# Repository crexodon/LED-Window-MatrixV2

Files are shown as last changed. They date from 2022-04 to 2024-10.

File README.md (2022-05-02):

# LED-Window-Matrix Neo
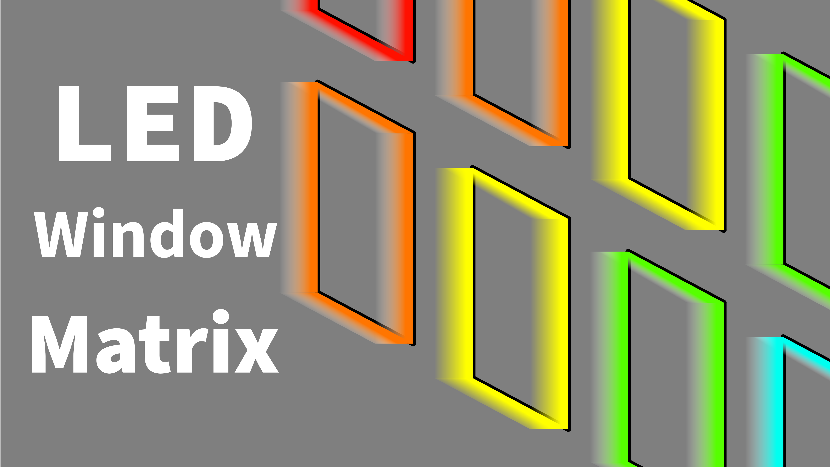
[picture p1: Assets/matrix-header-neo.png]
Header Image of Project

Complete new version of our last semester's [project](https://github.com/Boslx/LED-Window-Matrix). 

## New Features
- Complete rewrite of the mesh using ESP-MDF
- UDP based bridge for easy and fast communication
- Updated [PixelBridge](https://github.com/crexodon/PixelBridge)
- (Planned) Management Software for End User

## Old Media
https://user-images.githubusercontent.com/36489816/166237971-5a803816-1b47-4246-80e3-ec737a2a25ef.mp4

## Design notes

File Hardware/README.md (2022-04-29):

# Hardware
This folder contains our hardware designs for the matrix.

## Controller_Room
The room controller is a ESP32 PCB that features:  
- RS485 Transciever for the LEDs
- Power Switch and Sense
- Environment Sensors
- (Optional) LAN Interface
- (Optional) SD Card slot

## Controller_Window
The window controller is a WS2811 PCB that features:
- 2x RS485 Transciever for Data In and Out
- MosFETs to drive ~6m of RGB LED Strip

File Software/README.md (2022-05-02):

# Software
This folder contains the software for the matrix

## Mesh_Root
This is the root node of the mesh. It has a UDP Server to recieve packages from a user inside a wifi network and provides the relay to the mesh.

### UDP Protocol
The UDP protocol is still WIP, currently the structure is as follows:

```
 0  1  2  3  4  5  6  7  8  9 10
 
AA BB CC DD EE FF                   Target MAC
                  01                Command
                     00 01 02 ..    Payload
```

#### Commands
Command | Description | Payload | Example
--- | --- | --- | ---
0x01 | Set LED Data | Raw RGB LED data | `01 02 03 04 05 06 01 FF 00 00 00 FF 00 00 00 FF`
0x64 | Reset target node | N/A | `01 02 03 04 05 06 64`
0x65 | Initiate OTA (MAC is currently ignored) | Null terminated string of update URL | `00 00 00 00 00 00 65 http://192.168.1.100:8080/mesh_node.bin 00`

Commands can be easily sent with bash for testing, using echo and nc like this:  
`echo -ne "\x00\x00\x00\x00\x00\x00\x65http://192.168.1.100:8080/mesh_root.bin\x00" | nc -u -w0 192.168.1.42 7715`  

#### OTA Procedure

1. Build firmwares
2. **Upload node firmware to a local test node to see if it's still functional, before deploying to all nodes!**
3. Run `ota_fileserver.py`
4. Execute OTA UDP command with URL of OTA fileserver and path of firmware to update.
5. Depending of the filename of the update file, either the root or all nodes will be updated*

\* This behaviour will probably change in the future

## Mesh_Node
This is a mesh node. It can receive data from the mesh and parse them for the led control.

## PixelBridge
The [pixel bridge](https://github.com/crexodon/PixelBridge) is a fork of [LeoDJ's PixelBridge](https://github.com/LeoDJ/PixelBridge) that contains our contributions for this project. It is responsible for mapping the nodes to the rooms and also is a ArtNET endpoint for animations.

## Trinity
This is a management software that lets users control the matrix easier. It works together with the pixelbridge and also recieves data from the nodes' sensors
To Be Determined

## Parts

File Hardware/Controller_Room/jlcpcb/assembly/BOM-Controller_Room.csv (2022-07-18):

Comment | Designator | Footprint | LCSC
ACS711xLCTR-12AB | U4 | SOIC-8_3.9x4.9mm_P1.27mm | C114267
31,25k | R10 | R_0402_1005Metric | C11463
1k | R1,R19,R2,R20,R3 | R_0402_1005Metric | C11702
4.7u | L1 | L_0630 | C128688
Conn_01x04_Female | J4,J5 | JST_PH_B4B-PH-K_1x04_P2.00mm_Vertical | C131334
100n | C1,C11,C13,C15,C16,C17,C3,C4,C5,C7,C8,C9 | C_0402_1005Metric | C1525
10u | C10,C12,C14 | C_0402_1005Metric | C15525
Q_NPN_BEC | Q1 | SOT-23 | C2150
100 | R26 | C_0402_1005Metric | C25076
49R9 | R21,R22,R23,R24 | C_0402_1005Metric | C25120
100k | R4 | R_0402_1005Metric | C25741
10k | R11,R14,R18,R6 | R_0402_1005Metric | C25744
1.5k | R15 | C_0402_1005Metric | C25867
4k7 | R12,R13,R5,R7,R8 | C_0402_1005Metric | C25900
12k1 | R25 | C_0402_1005Metric | C281773
22u | C6 | CP_Elec_5x5.4 | C3001208
33 | R16,R17 | C_0402_1005Metric | C307331
Reset | SW1,SW2 | SW_SPST_TL3342 | C318887
RY8310 | IC1 | SOT-23-6 | C370876
Conn_01x04_Female | J6 | PhoenixContact_GMSTBA_2,5_4-G-7,62_1x04_P7.62mm_Horizontal | C395901
LAN8720A | U2 | QFN-24-1EP_4x4mm_P0.5mm_EP2.6x2.6mm | C45223
P-CHANNEL-MOSFET | M1,M2 | VSON-8_3.3x3.3mm_P0.65mm_NexFET | C471913
ESP32-WROOM-32 | U1 | ESP32-WROOM-32 | C473012
MAX3485 | U3 | SOIC-8_3.9x4.9mm_P1.27mm | C668204
Barrel_Jack_Switch | J1 | BarrelJack_10A | C706901
ASV-50MHz | X1 | Oscillator_SMD_Abracon_ASE-4Pin_3.2x2.5mm | C717684
LED | D1 | LED_0402_1005Metric | C71911
47u | C2 | CP_Elec_5x5.4 | C72515
LED | D3 | LED_0402_1005Metric | C74338
L_Ferrite | L2 | C_0402_1005Metric | C76891
LED | D2 | LED_0402_1005Metric | C88330
15V | D4 | D_0402_1005Metric
MountingHole | H1 | MountingHole_3.2mm_M3
Conn_01x06_Female | J7 | PinHeader_1x06_P2.54mm_Vertical
Conn_01x02_Female | J8 | PinHeader_1x02_P2.54mm_Vertical
MountingHole | H4 | MountingHole_3.2mm_M3
MountingHole | H3 | MountingHole_3.2mm_M3
Nc | R9 | R_0402_1005Metric
MountingHole | H2 | MountingHole_3.2mm_M3
Conn_01x04_Female | J10 | PinHeader_1x04_P2.54mm_Vertical
NC | C18 | C_0402_1005Metric
HR911105A | J2 | HR911105A

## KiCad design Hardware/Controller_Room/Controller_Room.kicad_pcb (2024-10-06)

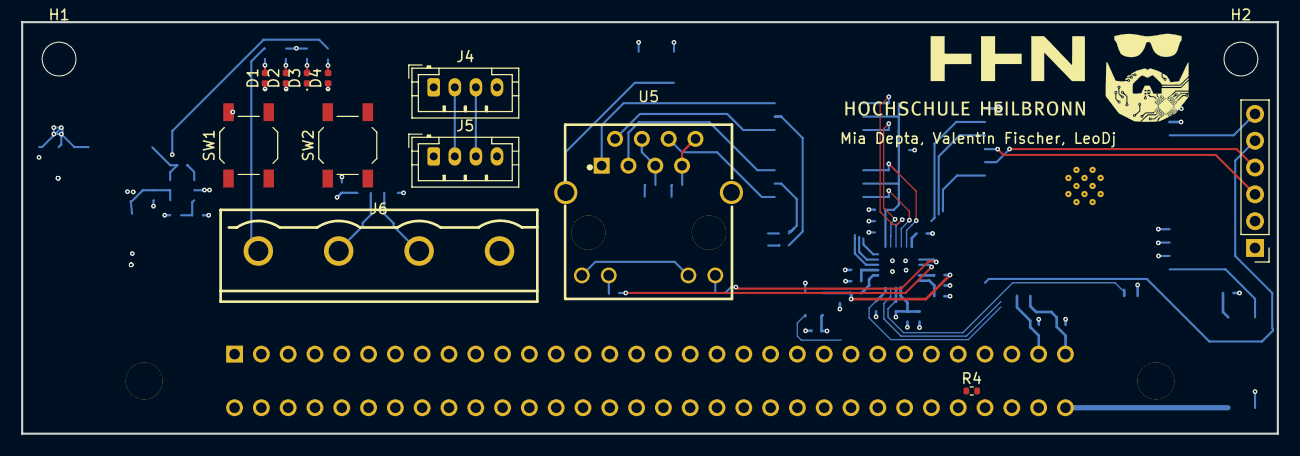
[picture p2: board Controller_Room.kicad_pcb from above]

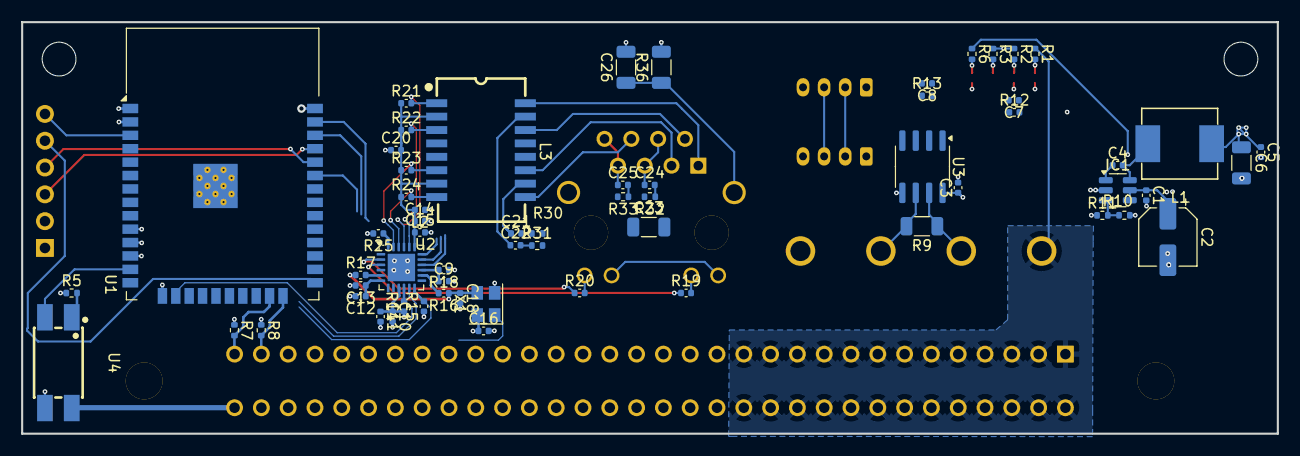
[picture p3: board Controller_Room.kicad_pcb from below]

Board: 4 copper layers, 119.0 x 39.0 mm, 79 parts (63 on the bottom side), 67 nets.

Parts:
C1, C3, C4, C5, C7, C8, C9, C11, C13, C15, C16, C20, C21, C22, C24, C25: 100n; C_0402_1005Metric
C2: 47u; CP_Elec_5x5.4
C6: 10u; C_1206_3216Metric
C10, C12, C14: 10u; C_0402_1005Metric
C18: NC; C_0402_1005Metric
C23, C26: 1000pF/2KV; C_1206_3216Metric
D1, D2, D3, D4: LED; LED_0402_1005Metric
H1, H2, H3, H4: MountingHole; MountingHole_3.2mm_M3
IC1: RY8310; SOT-23-6
J3: HP DPS; CONN-TH_64P-P2.54_ED64MEBGFBK
J4, J5: Conn_01x04_Female; JST_PH_B4B-PH-K_1x04_P2.00mm_Vertical
J6: Conn_01x04_Female; CONN-TH_4P-P7.62_DB2EVC-7.62-4P
J7: Conn_01x06_Female; PinHeader_1x06_P2.54mm_Vertical
L1: 4.7u; L_0630
L2: L_Ferrite; C_0402_1005Metric
L3: B1608S
R1, R6, R11: 10k; R_0402_1005Metric
R2, R3: 1k; R_0402_1005Metric
R4: 22k; R_0402_1005Metric
R5: R; R_0402_1005Metric
R7, R8: 4k7; R_0402_1005Metric
R9: Nc; R_1206_3216Metric
R10: 31,25k; R_0402_1005Metric
R12, R13: 4k7; C_0402_1005Metric
R14, R18: 10k; C_0402_1005Metric
R15: 1.5k; C_0402_1005Metric
R16, R17: 33; C_0402_1005Metric
R19, R20: 1k; C_0402_1005Metric
R21, R22, R23, R24: 49R9; C_0402_1005Metric
R25: 12k1; C_0402_1005Metric
R30, R31, R32, R33: 75; R_0402_1005Metric
R36: 0; C_1206_3216Metric
SW1: Reset; SW_SPST_TL3342
SW2: User; SW_SPST_TL3342
U1: ESP32-WROOM-32
U2: LAN8720A; QFN-24-1EP_4x4mm_P0.5mm_EP2.6x2.6mm
U3: MAX3485; SOIC-8_3.9x4.9mm_P1.27mm
U4: EL817S1(C)(TU)-F; OPTO-SMD-4_L4.6-W6.5-P2.54-LS10.3-TL
U5: RC01931; RJ45-TH_RCH_RC01931
X1: ASV-50MHz; Oscillator_SMD_Abracon_ASE-4Pin_3.2x2.5mm

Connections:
+3.3VA: C14.1, C15.1, C20.2, L2.2, L3.2 (TCT), L3.7 (RCT), R21.1, R22.1, R23.1, R24.1, U2.1 (VDD2A), U2.19 (VDD1A), U5.9 (LED+), U5.11 (LED+)
+3V3: C3.1, C5.1, C6.1, C10.1, C11.1, C16.1, J4.1, J5.1, J7.1, L1.2, L2.1, R2.1, R3.1, R5.1, R7.1, R8.1, R10.2, R12.1, R13.1, R14.1, R15.1, R18.1, U1.2 (VDD), U2.9 (VDDIO), U3.8 (VCC), X1.4 (Vdd)
+12V: C1.1, C2.1, IC1.4 (EN), IC1.5 (IN), J3.56, R4.1, R6.1
+VSW: J3.1, J3.2, J3.3, J3.4, J3.5, J3.6, J3.7, J3.8, J3.9, J3.10, J3.11, J3.12, J3.13, J3.14, J3.15, J3.16, J3.17, J3.18, J3.19, J3.20, J3.21, J3.22, J3.23, J3.24, J3.25, J3.26, J6.1, R1.1
/HP DPS High/PRESENT#: J3.58, R4.2
/HP DPS High/PSON#: J3.64, U4.4 (COL)
A: J6.3, R9.2, U3.6 (A)
B: J6.2, R9.1, U3.7 (B)
CLK50M: C18.1, R16.1, R17.1, X1.3 (OUT)
EN: C7.1, J7.6, R12.2, SW1.2, U1.3 (EN)
ETHLEDGreen: R19.2, U5.10 (LED-)
ETHLEDYel: R20.2, U5.12 (LED-)
Earth: C23.2, C26.1, R36.1, U5.13, U5.14
GND: C1.2, C2.2, C3.2, C5.2, C6.2, C7.2, C8.2, C9.2, C10.2, C11.2, C12.2, C13.2, C14.2, C15.2, C16.2, C18.2, C20.1, C26.2, D1.1 (K), D2.1 (K), D4.1 (K), IC1.2 (GND), J3.27, J3.28, J3.29, J3.30, J3.31, J3.32, J3.33, J3.34, J3.35, J3.36, J3.37, J3.38, J3.39, J3.40, J3.41, J3.42, J3.43, J3.44, J3.45, J3.46, J3.47, J3.48, J3.49, J3.50, J3.51, J3.52, J3.59, J4.4, J5.4, J6.4, J7.2, R11.1, R25.2, R36.2, SW1.1, SW2.1, U1.1 (GND), U1.15 (GND), U1.38 (GND), U1.39 (GND), U2.25 (VSS), U3.5 (GND), U4.3 (EM), X1.2 (GND)
IO0: J7.5, R16.2, U1.25 (IO0), U2.14 (INT/REFCLKO)
IO13_RXER: R14.2, U1.16 (IO13), U2.10 (RXER/PHYAD0)
IO16_OSC_EN: U1.27 (IO16), X1.1 (EN)
IO18_MDIO: R15.2, U1.30 (IO18), U2.12 (MDIO)
IO19_TXD0: U1.31 (IO19), U2.17 (TXD0)
IO21_TXEN: U1.33 (IO21), U2.16 (TXEN)
IO22_TXD1: U1.36 (IO22), U2.18 (TXD1)
IO23_MDC: U1.37 (IO23), U2.13 (MDC)
IO25_RXD0: U1.10 (IO25), U2.8 (RXD0/MODE0)
IO26_RXD1: U1.11 (IO26), U2.7 (RXD1/MODE1)
IO27_CRS_DV: U1.12 (IO27), U2.11 (CRS_DV/MODE2)
unnamed: C21.2, R30.1
unnamed: C22.2, R31.1
unnamed: C23.1, R30.2, R31.2, R32.2, R33.2
unnamed: C24.1, U5.4, U5.5
unnamed: C24.2, R32.1
unnamed: C25.1, U5.7, U5.8
unnamed: C25.2, R33.1
unnamed: D1.2 (A), R1.2
unnamed: D2.2 (A), R2.2
unnamed: D3.2 (A), R3.2
unnamed: D4.2 (A), R6.2
unnamed: C4.1, IC1.1 (CB)
unnamed: IC1.3 (FB), R10.1, R11.2
unnamed: C4.2, IC1.6 (SW), L1.1
unnamed: L3.11 (RX+), U5.3
unnamed: L3.9 (RX-), U5.6
unnamed: C21.1, L3.10 (RXCT)
unnamed: L3.16 (TX+), U5.1
unnamed: L3.14 (TX-), U5.2
unnamed: C22.1, L3.15 (TXCT)
unnamed: R19.1, U2.3 (LED1/REGOFF)
unnamed: R20.1, U2.2 (LED2/nINTSEL)
unnamed: R25.1, U2.24 (RBIAS)
unnamed: C12.1, C13.1, U2.6 (VDDCR)
unnamed: R5.2, U4.1 (AN)
OSCIN: R17.2, U2.5 (XTAL1/CLKIN)
PowerSW: U1.13 (IO14), U4.2 (CAT)
RS485_DE: U1.8 (IO32), U3.3 (DE)
RS485_DI: U1.26 (IO4), U3.4 (DI)
RS485_RE: U1.9 (IO33), U3.2 (~RE)
RS485_RO: U1.14 (IO12), U3.1 (RO)
RX: J7.4, U1.34 (RXD0/IO3)
RXN: L3.8 (RD-), R24.2, U2.22 (RXN)
RXP: L3.6 (RD+), R23.2, U2.23 (RXP)
SCL: J3.63, J4.3, J5.3, R7.2, U1.23 (IO15)
SDA: J3.61, J4.2, J5.2, R8.2, U1.24 (IO2)
StateLED: D3.1 (K), U1.28 (IO17)
TX: J7.3, U1.35 (TXD0/IO1)
TXN: L3.3 (TD-), R22.2, U2.20 (TXN)
TXP: L3.1 (TD+), R21.2, U2.21 (TXP)
UserButton: C8.1, R13.2, SW2.2, U1.4 (SENSOR_VP)
nRST: C9.1, R18.2, U2.15 (RST)

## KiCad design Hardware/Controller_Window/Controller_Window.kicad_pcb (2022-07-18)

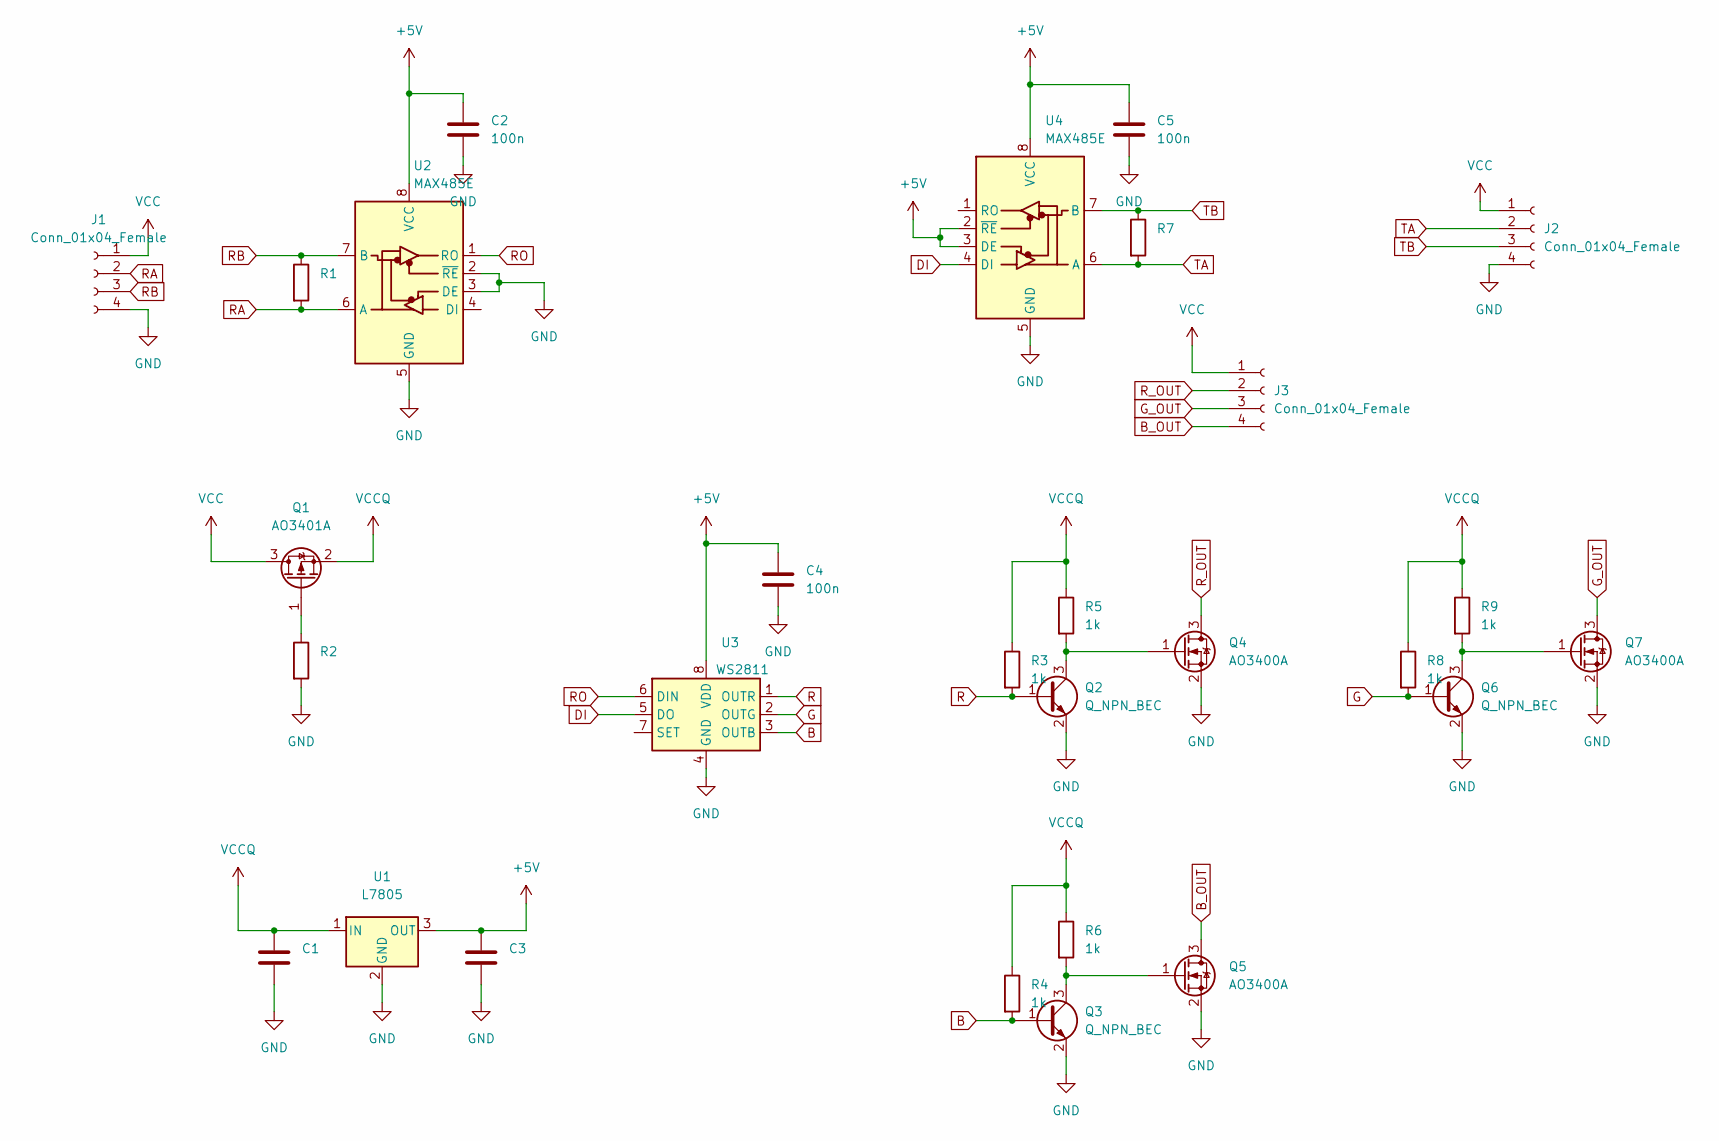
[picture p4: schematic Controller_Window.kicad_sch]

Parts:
C1, C3: C_0402_1005Metric
C2, C4, C5: 100n; C_0402_1005Metric
J1, J2: Conn_01x04_Female; PhoenixContact_GMSTBA_2,5_4-G-7,62_1x04_P7.62mm_Horizontal
J3: Conn_01x04_Female; JST_PH_S4B-PH-K_1x04_P2.00mm_Horizontal
Q1: AO3401A; SOT-23
Q2, Q3, Q6: Q_NPN_BEC; TSOT-23
Q4, Q5, Q7: AO3400A; SOT-23
R1, R2, R7: C_0402_1005Metric
R3, R4, R5, R6, R8, R9: 1k; C_0402_1005Metric
U1: L7805; TO-252-2
U2, U4: MAX485E; SOIC-8_3.9x4.9mm_P1.27mm
U3: WS2811; SOIC-8_3.9x4.9mm_P1.27mm

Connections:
+5V: C2.1, C3.1, C4.1, C5.1, U1.3 (OUT), U2.8 (VCC), U3.8 (VDD), U4.2 (~RE), U4.3 (DE), U4.8 (VCC)
B: Q3.1 (B), R4.2, U3.3 (OUTB)
B_OUT: J3.4, Q5.3 (D)
DI: U3.5 (DO), U4.4 (DI)
G: Q6.1 (B), R8.2, U3.2 (OUTG)
GND: C1.2, C2.2, C3.2, C4.2, C5.2, J1.4, J2.4, Q2.2 (E), Q3.2 (E), Q4.2 (S), Q5.2 (S), Q6.2 (E), Q7.2 (S), R2.2, U1.2 (GND), U2.2 (~RE), U2.3 (DE), U2.5 (GND), U3.4 (GND), U4.5 (GND)
G_OUT: J3.3, Q7.3 (D)
unnamed: Q1.1 (G), R2.1
unnamed: Q2.3 (C), Q4.1 (G), R5.2
unnamed: Q3.3 (C), Q5.1 (G), R6.2
unnamed: Q6.3 (C), Q7.1 (G), R9.2
R: Q2.1 (B), R3.2, U3.1 (OUTR)
RA: J1.2, R1.2, U2.6 (A)
RB: J1.3, R1.1, U2.7 (B)
RO: U2.1 (RO), U3.6 (DIN)
R_OUT: J3.2, Q4.3 (D)
TA: J2.2, R7.2, U4.6 (A)
TB: J2.3, R7.1, U4.7 (B)
VCC: J1.1, J2.1, J3.1, Q1.3 (D)
VCCQ: C1.1, Q1.2 (S), R3.1, R4.1, R5.1, R6.1, R8.1, R9.1, U1.1 (IN)

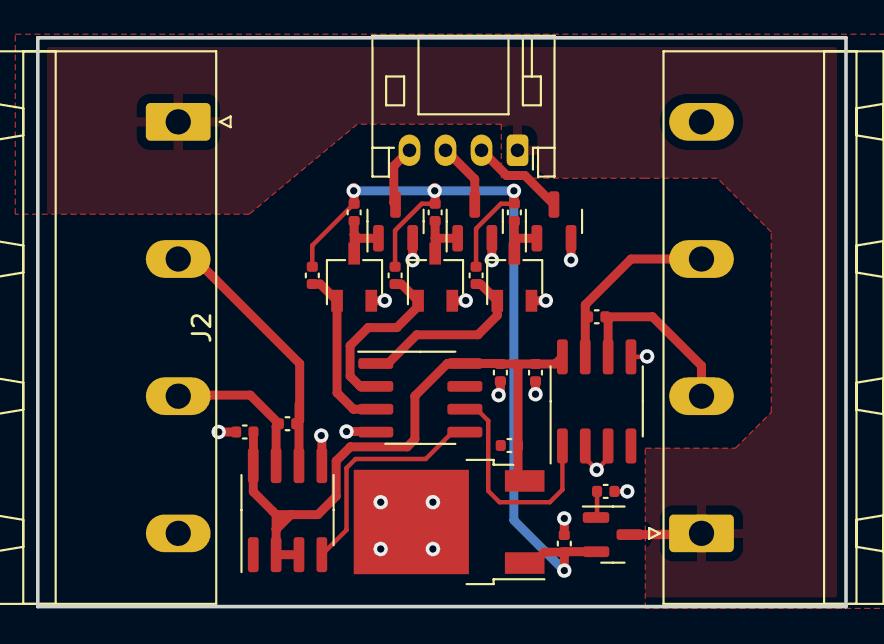
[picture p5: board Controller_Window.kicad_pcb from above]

Board: 2 copper layers, 44.9 x 31.6 mm, 28 parts (0 on the bottom side), 20 nets.

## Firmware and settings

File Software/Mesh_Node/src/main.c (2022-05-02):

// Copyright 2017 Espressif Systems (Shanghai) PTE LTD
//
// Licensed under the Apache License, Version 2.0 (the "License");
// you may not use this file except in compliance with the License.
// You may obtain a copy of the License at

//     http://www.apache.org/licenses/LICENSE-2.0
//
// Unless required by applicable law or agreed to in writing, software
// distributed under the License is distributed on an "AS IS" BASIS,
// WITHOUT WARRANTIES OR CONDITIONS OF ANY KIND, either express or implied.
// See the License for the specific language governing permissions and
// limitations under the License.

#include "mdf_common.h"
#include "mwifi.h"
#include "mupgrade.h"

#include "globals.h"
#include "led.h"

// #define MEMORY_DEBUG

typedef struct {
    uint8_t command;
    uint8_t data[];
} ledMeshPayload_t;

// static const uint8_t ledMeshPayloadHeaderSize = sizeof(ledMeshPayload_t);


static void node_read_task(void *arg)
{
    mdf_err_t ret = MDF_OK;
    char *data    = MDF_MALLOC(MWIFI_PAYLOAD_LEN);
    size_t size   = MWIFI_PAYLOAD_LEN;
    mwifi_data_type_t data_type      = {0x0};
    uint8_t src_addr[MWIFI_ADDR_LEN] = {0x0};

    MDF_LOGI("Note read task is running");

    for (;;) {
        if (!mwifi_is_connected()) {
            vTaskDelay(500 / portTICK_RATE_MS);
            continue;
        }

        size = MWIFI_PAYLOAD_LEN;
        memset(data, 0, MWIFI_PAYLOAD_LEN);
        ret = mwifi_read(src_addr, &data_type, data, &size, portMAX_DELAY);
        MDF_ERROR_CONTINUE(ret != MDF_OK, "mwifi_read, ret: %x", ret);
        if (data_type.upgrade) {
            ret = mupgrade_handle(src_addr, data, size);
            MDF_ERROR_CONTINUE(ret != MDF_OK, "<%s> mupgrade_handle", mdf_err_to_name(ret));
        }
        else {
            MDF_LOGI("Node receive, addr: " MACSTR ", size: %d, data: %s", MAC2STR(src_addr), size, data);

            switch (data_type.custom) {
                case CMD_LedData:
                    ledSetData((uint8_t*)data, size);
                    break;
                case CMD_Restart:
                    MDF_LOGI("Restarting the node...");
                    MDF_LOGW("The device will restart after 1 seconds");
                    vTaskDelay(pdMS_TO_TICKS(1000));
                    esp_restart();
            }
        }
    }

    MDF_LOGW("Note read task is exit");

    MDF_FREE(data);
    vTaskDelete(NULL);
}

void node_write_task(void *arg)
{
    mdf_err_t ret = MDF_OK;
    int count     = 0;
    size_t size   = 0;
    char *data    = MDF_MALLOC(MWIFI_PAYLOAD_LEN);
    mwifi_data_type_t data_type = {0x0};

    MDF_LOGI("Node write task is running");

    for (;;) {
        if (!mwifi_is_connected()) {
            vTaskDelay(500 / portTICK_RATE_MS);
            continue;
        }

        // size = sprintf(data, "(%d) Hello root!", count++);
        // ret = mwifi_write(NULL, &data_type, data, size, true);
        // MDF_ERROR_CONTINUE(ret != MDF_OK, "mwifi_write, ret: %x", ret);

        vTaskDelay(1000 / portTICK_RATE_MS);
    }

    MDF_LOGW("Node write task is exit");

    MDF_FREE(data);
    vTaskDelete(NULL);
}

/**
 * @brief Timed printing system information
 */
static void print_system_info_timercb(void *timer)
{
    uint8_t primary                 = 0;
    wifi_second_chan_t second       = 0;
    mesh_addr_t parent_bssid        = {0};
    uint8_t sta_mac[MWIFI_ADDR_LEN] = {0};
    wifi_sta_list_t wifi_sta_list   = {0x0};

    esp_wifi_get_mac(ESP_IF_WIFI_STA, sta_mac);
    esp_wifi_ap_get_sta_list(&wifi_sta_list);
    esp_wifi_get_channel(&primary, &second);
    esp_mesh_get_parent_bssid(&parent_bssid);

    MDF_LOGI("System information, channel: %d, layer: %d, self mac: " MACSTR ", parent bssid: " MACSTR
             ", parent rssi: %d, node num: %d, free heap: %u", primary,
             esp_mesh_get_layer(), MAC2STR(sta_mac), MAC2STR(parent_bssid.addr),
             mwifi_get_parent_rssi(), esp_mesh_get_total_node_num(), esp_get_free_heap_size());

    for (int i = 0; i < wifi_sta_list.num; i++) {
        MDF_LOGI("Child mac: " MACSTR, MAC2STR(wifi_sta_list.sta[i].mac));
    }

#ifdef MEMORY_DEBUG

    if (!heap_caps_check_integrity_all(true)) {
        MDF_LOGE("At least one heap is corrupt");
    }

    mdf_mem_print_heap();
    mdf_mem_print_record();
    mdf_mem_print_task();
#endif /**< MEMORY_DEBUG */
}

static mdf_err_t wifi_init()
{
    mdf_err_t ret          = nvs_flash_init();
    wifi_init_config_t cfg = WIFI_INIT_CONFIG_DEFAULT();

    if (ret == ESP_ERR_NVS_NO_FREE_PAGES || ret == ESP_ERR_NVS_NEW_VERSION_FOUND) {
        MDF_ERROR_ASSERT(nvs_flash_erase());
        ret = nvs_flash_init();
    }

    MDF_ERROR_ASSERT(ret);

    MDF_ERROR_ASSERT(esp_netif_init());
    MDF_ERROR_ASSERT(esp_event_loop_create_default());
    MDF_ERROR_ASSERT(esp_wifi_init(&cfg));
    MDF_ERROR_ASSERT(esp_wifi_set_storage(WIFI_STORAGE_FLASH));
    MDF_ERROR_ASSERT(esp_wifi_set_mode(WIFI_MODE_STA));
    MDF_ERROR_ASSERT(esp_wifi_set_ps(WIFI_PS_NONE));
    MDF_ERROR_ASSERT(esp_mesh_set_6m_rate(false));
    MDF_ERROR_ASSERT(esp_wifi_start());

    return MDF_OK;
}

/**
 * @brief All module events will be sent to this task in esp-mdf
 *
 * @Note:
 *     1. Do not block or lengthy operations in the callback function.
 *     2. Do not consume a lot of memory in the callback function.
 *        The task memory of the callback function is only 4KB.
 */
static mdf_err_t event_loop_cb(mdf_event_loop_t event, void *ctx)
{
    MDF_LOGI("event_loop_cb, event: %d", event);

    switch (event) {
        case MDF_EVENT_MWIFI_STARTED:
            MDF_LOGI("MESH is started");
            break;

        case MDF_EVENT_MWIFI_PARENT_CONNECTED:
            MDF_LOGI("Parent is connected on station interface");
            break;

        case MDF_EVENT_MWIFI_PARENT_DISCONNECTED:
            MDF_LOGI("Parent is disconnected on station interface");
            break;

        default:
            break;
    }

    return MDF_OK;
}

void app_main()
{
    mwifi_init_config_t cfg = MWIFI_INIT_CONFIG_DEFAULT();
    mwifi_config_t config   = {
        .channel   = CONFIG_MESH_CHANNEL,
        .mesh_id   = CONFIG_MESH_ID,
        .mesh_type = CONFIG_DEVICE_TYPE,
    };

    /**
     * @brief Set the log level for serial port printing.
     */
    esp_log_level_set("*", ESP_LOG_INFO);
    esp_log_level_set(TAG, ESP_LOG_DEBUG);
    esp_log_level_set("mupgrade_root", ESP_LOG_DEBUG);
    esp_log_level_set("mupgrade_node", ESP_LOG_DEBUG);

    /**
     * @brief Initialize wifi mesh.
     */
    MDF_ERROR_ASSERT(mdf_event_loop_init(event_loop_cb));
    MDF_ERROR_ASSERT(wifi_init());
    MDF_ERROR_ASSERT(mwifi_init(&cfg));
    MDF_ERROR_ASSERT(mwifi_set_config(&config));
    MDF_ERROR_ASSERT(mwifi_start());

    /**
     * @brief Data transfer between wifi mesh devices
     */

    xTaskCreate(node_write_task, "node_write_task", 4 * 1024,
                NULL, CONFIG_MDF_TASK_DEFAULT_PRIOTY, NULL);
    xTaskCreate(node_read_task, "node_read_task", 4 * 1024,
                NULL, CONFIG_MDF_TASK_DEFAULT_PRIOTY, NULL);

    TimerHandle_t timer = xTimerCreate("print_system_info", 10000 / portTICK_RATE_MS,
                                       true, NULL, print_system_info_timercb);
    xTimerStart(timer, 0);

    ledInit();
}

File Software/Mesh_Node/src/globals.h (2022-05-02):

static const char *TAG = "mesh_node";


#define LED_PIN         16
#define LED_NUM         32
#define RMT_TX_CHANNEL  RMT_CHANNEL_0


enum LedPayloadCommand {
    CMD_LedData = 1,
    CMD_Restart = 100,
};

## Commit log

2022-04-29 initialize two PIO ESP-MDF projects
    Template: https://github.com/maxgerhardt/pio-esp-mdf-example
    [partitions.csv]
2022-04-29 rename folders and add pixel bridge submodule
    [partitions.csv]
2022-05-01 implement basic LED control over mesh
2022-05-01 implement basic OTA functionality
    currently also updates the root node by mistake with node firmware. TODO: fix
    [globals.h, main.c]
2022-05-02 fix reset command needing dummy byte
    remove unnecessary debug print
2022-05-02 add documentation for current UDP protocol
2022-07-18 add Hardware
    [BOM-Controller_Room.csv, BOM-Controller_Window.csv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]
2022-10-31 fix Bodges in Schematic
    [Controller_Room.kicad_sch]
2022-11-02 fix bugs
    [Window_Tester.kicad_pcb, Window_Tester.kicad_sch]
